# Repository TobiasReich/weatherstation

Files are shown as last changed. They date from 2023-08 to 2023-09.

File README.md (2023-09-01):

# Weatherstation

As part of my studies I wanted to experiment with the smallest devices and sensors I could get.
This became a local (indoor) weather station built up with an ESP32 and sensors.

If you are looking for a cheap weather station you might find this somewhere else. This is more a hobby, a kind of a playground for sensors and C programming.

## Overview

The idea is to
- use a cheap and low energy consuming ESP32 as base
- use a bunch of sensors for getting an idea of the environment
- draw the data on a waveshare e-paper display

## Devices

1. ESP32 device:
https://www.waveshare.com/wiki/E-Paper_ESP32_Driver_Board

1. E-Paper display:
I used the 400x300 pixel e-paper display from Waveshare: https://www.waveshare.com/4.2inch-e-paper-module.htm

1. Sensors:

I used the following sensors:

- Thermometer
- Barometer
- ~~Raindrop Sensor~~
- Humidity Sensor
- Soil Humidity sensor (for knowing whether I have to water the plants)
- Air Quality sensor (CO2 and TVOC)

Many came from here:

https://www.sunfounder.com/products/sensor-kit-v2-for-arduino?_pos=2&_sid=1bdf16cc9&_ss=r

Furthermore the device uses a soil moisture senesor from here:

https://www.seeedstudio.com/Grove-Capacitive-Moisture-Sensor-Corrosion-Resistant.html

And an air quality sensor from here:

https://wiki.seeedstudio.com/Grove-VOC_and_eCO2_Gas_Sensor-SGP30/

# Pinouts

This is not the exact model but it seems to have the same pinout. Sadly the documentation on Waveshare is not the best.

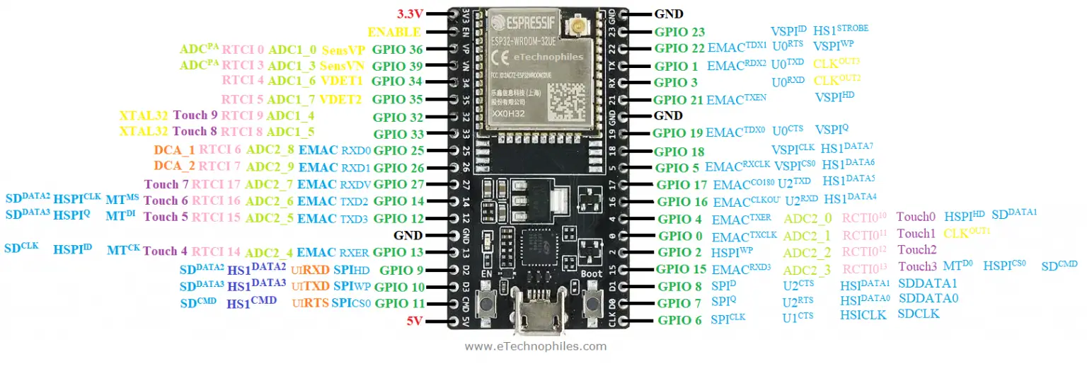
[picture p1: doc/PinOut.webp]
Pinout


The schematics look currently like that:
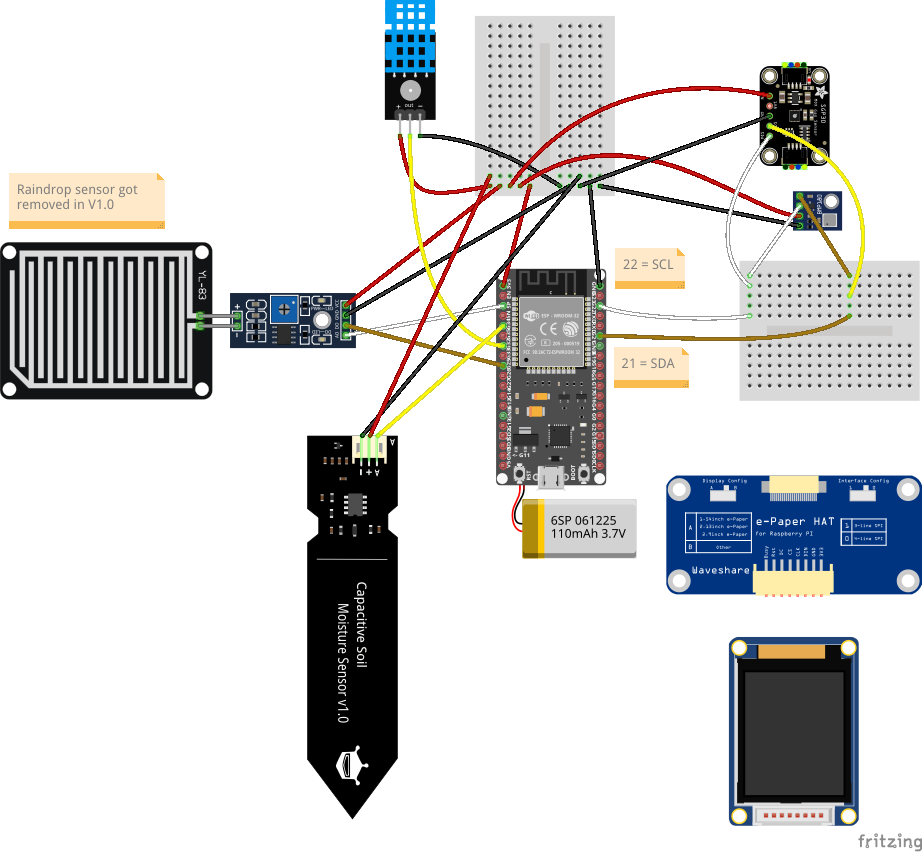
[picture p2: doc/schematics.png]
Schematics


The first version of it (which is in usage) looks like that (and in German only).

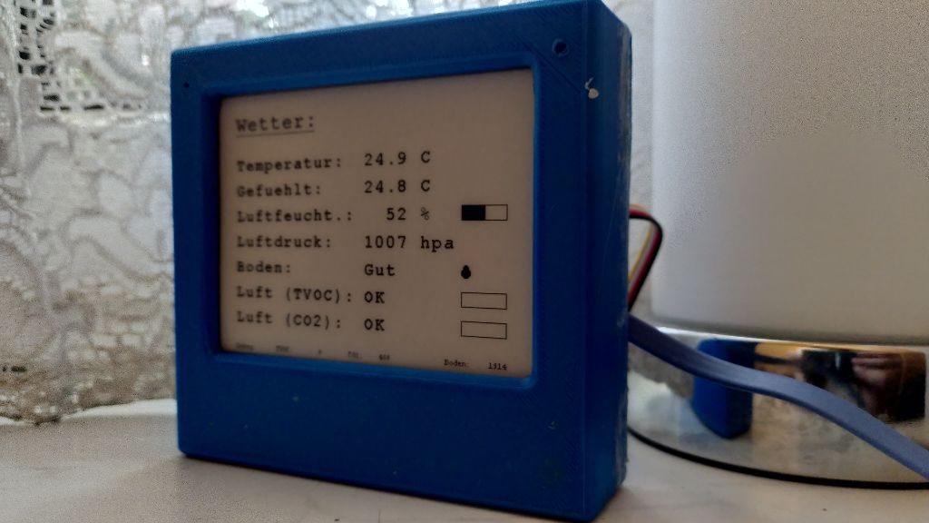
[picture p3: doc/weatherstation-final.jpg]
First test The final usage


Version 2 also got a graph showing the recent 10 hours (20 measurements) for TVOC and CO2 readings.
That way you can keep track of the situation. This might come handy in situations where you have the suspicion of raising values (e.g. over night, with a closed window).
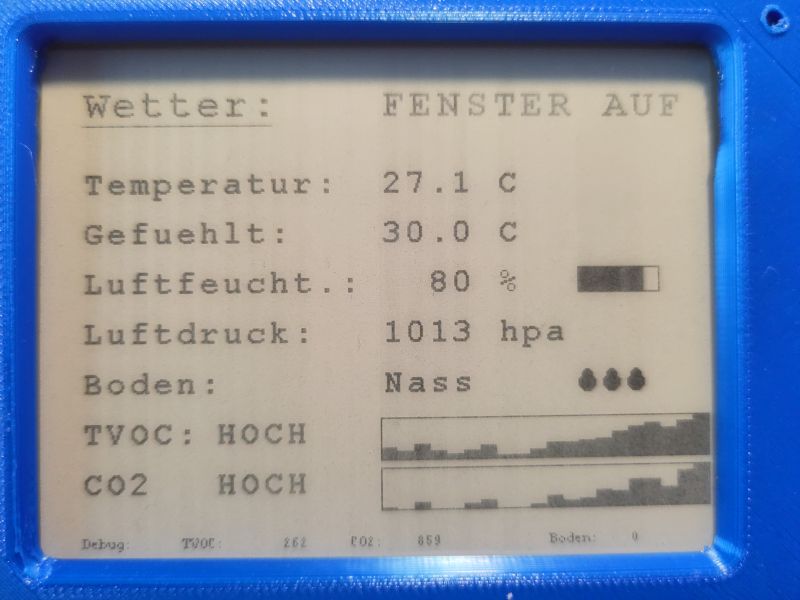
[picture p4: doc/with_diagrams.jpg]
Version 2 adding a diagram


## Barometer

- Black - GROUND
- Red - 3.3V
- White - GPIO 21 (DEFAULT SDA)
- Brown - GPIO 22 (DEFAULT SCL)
- I2C: 0x77

## ~~Raindrop Sensor~~

~~This is connected via a Raindrop Sensor (which connects again to the device).~~

- Black - GROUND
- Red - 3.3V
- White - GPIO 36 (ANALOG AO)
- Brown - GPIO 25 (D0)

Note: I removed it since it was not very useful. Placing it indoors made no sense, outdoors not much either (you see it anyway, you can measure it with the soil moisture sensor...). It just made things more complex and was useless.

## Humidity Sensor

- Black - GROUND
- Red - 3.3V
- Yellow - GPIO 32

## Soil Moisture Sensor

- Black - GROUND
- Red - 3.3V
- White - GPIO ??
- Brown - GPIO ??

Note that the soil moisture sensor is just an analog one. It checks the resistence and varies for example if you provide 3.3V or 5V to it.
Hence the setup might vary your constants.

I plugged it to 3.3 volt and defined the constants as

- SOIL_DRYNESS_HIGH 2000

- SOIL_DRYNESS_MEDIUM 1150

where the analog value goes higher the dryer the ground is.

## Air Quality Sensor

- Black - GROUND
- Red - 3.3V
- White - GPIO 21 (DEFAULT SDA)
- Brown - GPIO 22 (DEFAULT SCL)
- I2C: 0x58

NOTE: they share the same

I also calculate the "air quality" by very simple means.

These are the constants I use:

- VOC_LOW 25

- VOC_MED 75

- CO2_LOW 450

- CO2_MED 550

And I draw them on the display in a very simple graph, indicating the quality.
This surely can be done better.

# Known issues:

1. When there is rain on the rain sensor, the voltage it draws seems to be too high and the display doesn't refresh anymore. I therefore (and for it's limited usage) removed the sensor for version 1.

2. Also the case I printed comes with some drawbacks. Even as a physics enthusiast it took a while to realize that CO2 is heavier than O2. And with basically no opening in the case the CO2 value was rising over the time to higher and higher values. In any case you should avoid placing the air quality sensor at the bottom of the case! And add some holes to the rear side.

3. Turns out, the glue I was using for fusing the PLA casing, is evaporating "volatile particles" thus influencing the TVOC reading. A quick fix would be either to move the sensor outside or use a different glue. I guess in the long term it will reduce it's evaporation, too but the best solution might be a better case (with lots of openings and less glue required).

4. Furthermore you need to make sure the temperature sensor is not too close to the ESP32. In my example the heat from the processor is radiating to the temperature sensor leading to 1-2 degrees higher temperature.

I originally thought I could put it inside like this:

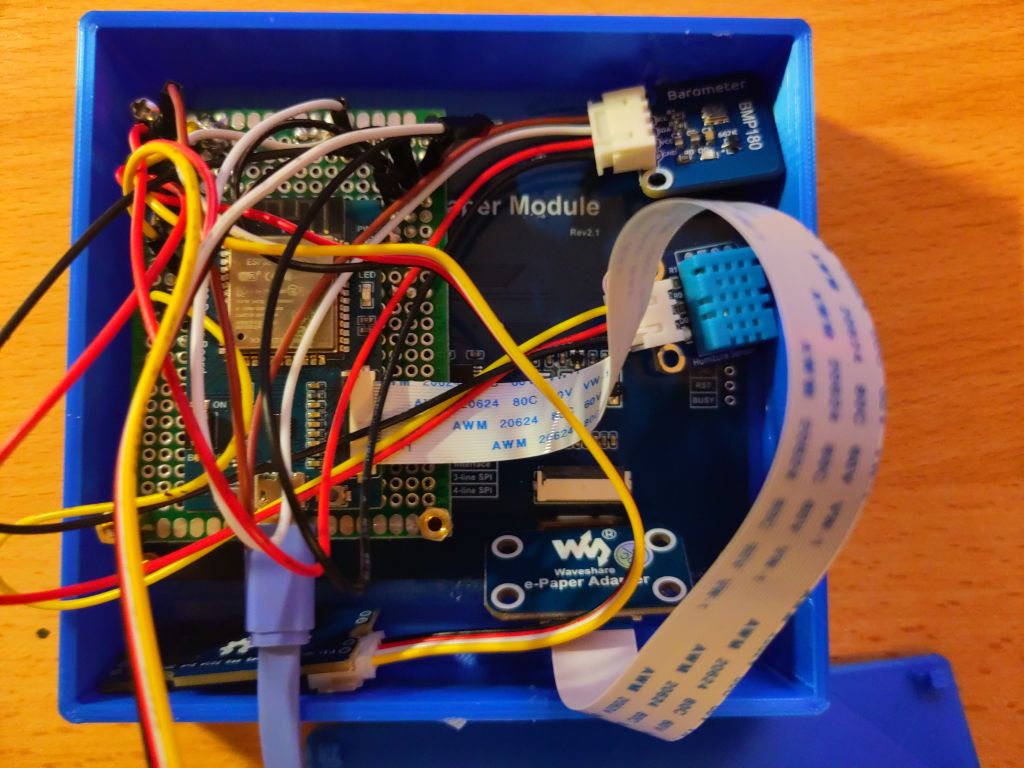
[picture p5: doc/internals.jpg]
First test the planned interior.


which would be still not great but not horrible either. However, with the tiny case I had to squeeze eveything to gether ending up with a crammed case where everything is right next to eachother. Version 2 has to be a little bigger!

# Schematics

I tried to use Fritzing for a better schematics diagram.

Since the software lacks some of the components I need, I used many of these repositories:

https://github.com/sunfounder/sunfounder-uno-and-mega-kit
https://github.com/jorgechacblogspot/librerias_fritzing
https://github.com/OgreTransporter/fritzing-parts-extra/tree/master
https://github.com/Seeed-Studio/fritzing_parts

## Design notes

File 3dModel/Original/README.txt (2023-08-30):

4.2" E-Paper Weather Station w/ ESP32 - Case by Wi_Zeus on Thingiverse: https://www.thingiverse.com/thing:2954579

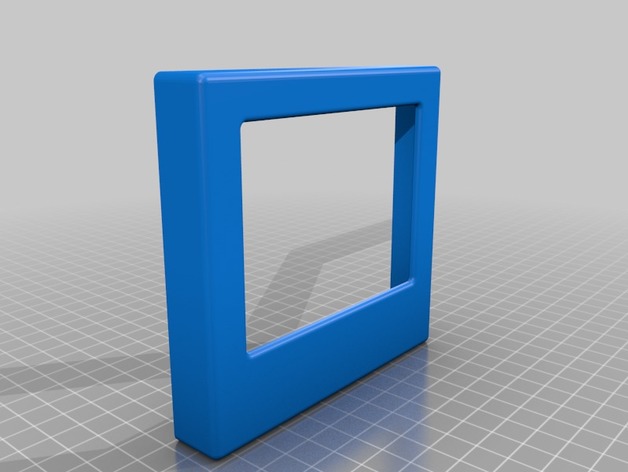
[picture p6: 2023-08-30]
3dModel/Original/images/4.2_Epaper_Weather_Station_Main_V3.jpg

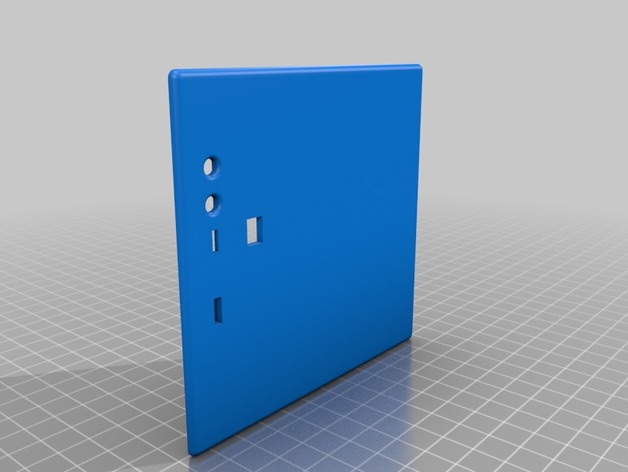
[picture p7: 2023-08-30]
3dModel/Original/images/4.2_Epaper_Weather_Station_Back_V3.jpg

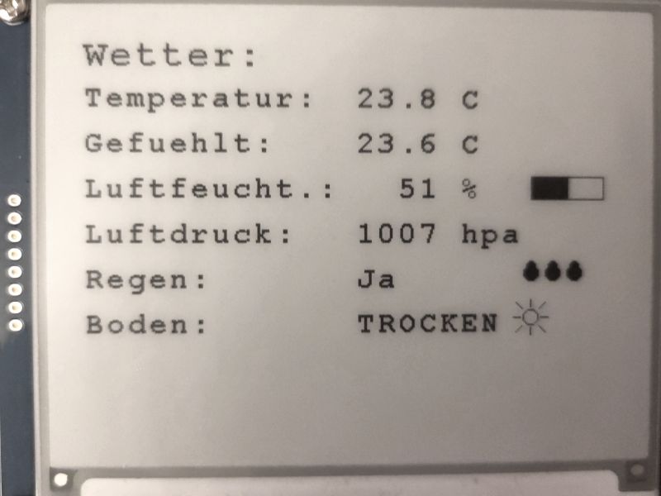
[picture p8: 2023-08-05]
doc/weatherstation-alpha01.jpg

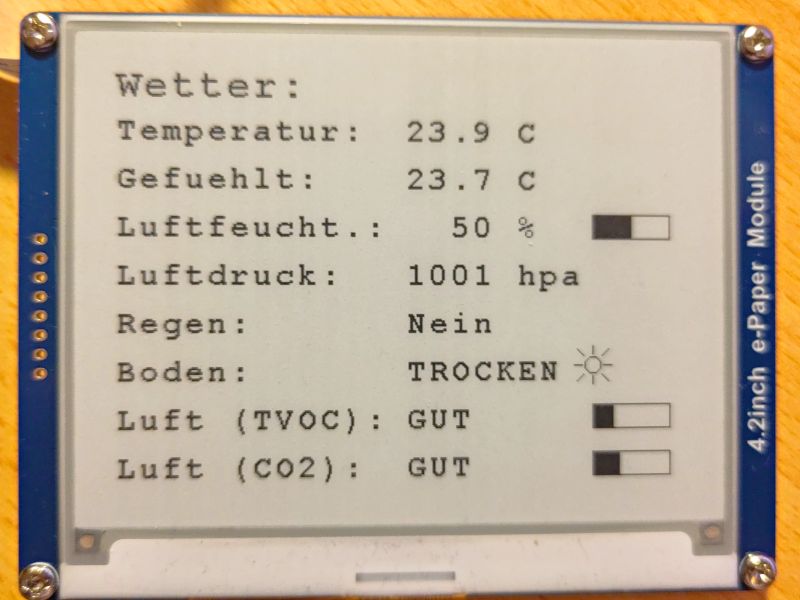
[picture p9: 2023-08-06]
doc/weatherstation-alpha02.jpg

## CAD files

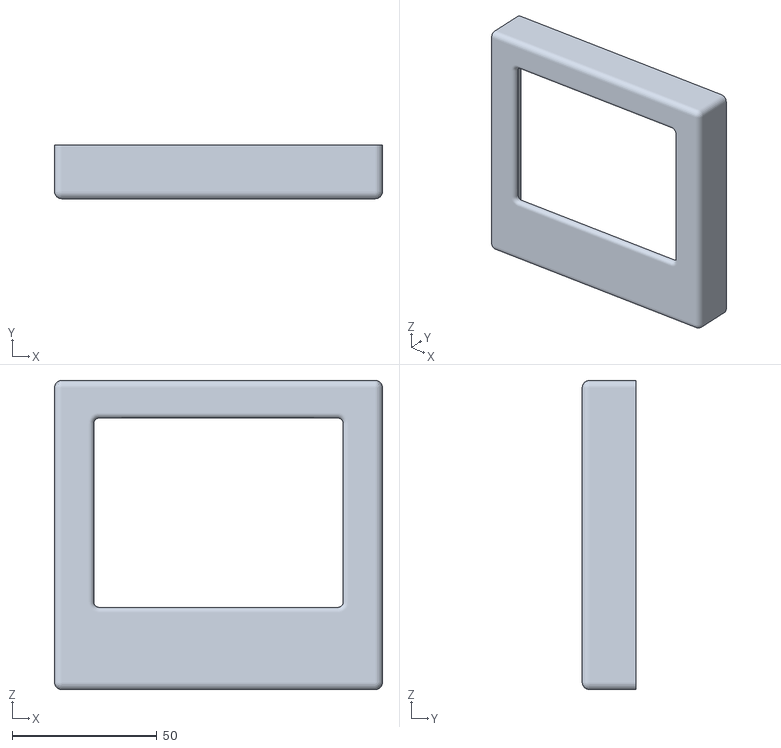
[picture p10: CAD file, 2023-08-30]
3dModel/Original/4.2_Epaper_Weather_Station_Main_V3.stl
113.2 x 18.5 x 106.7

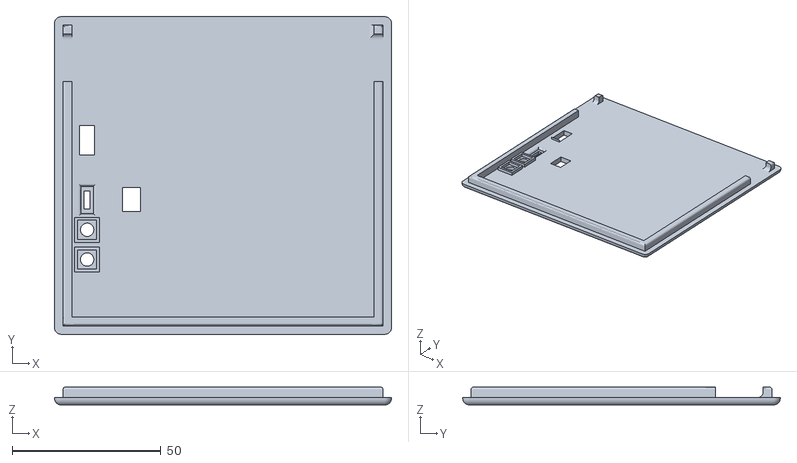
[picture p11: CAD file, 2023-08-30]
3dModel/GroveCutout/Back-GroveCutout.stl
113.2 x 106.7 x 6.00

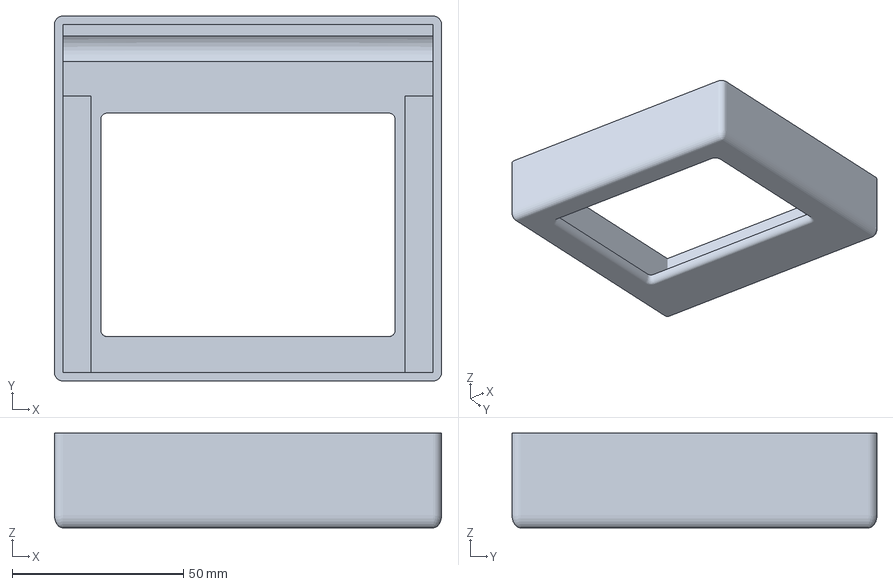
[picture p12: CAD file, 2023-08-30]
3dModel/Weatherstation-Front-150percent.3mf
113.2 x 106.7 x 27.8 mm

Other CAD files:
3dModel/Original/4.2_Epaper_Weather_Station_Back_V3.stl
3dModel/GroveCutout/Back-GroveCutout.blend

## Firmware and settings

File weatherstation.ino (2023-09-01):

#include <Adafruit_SGP30.h>
#include "DEV_Config.h"
#include "EPD.h"
#include "GUI_Paint.h"
#include "ImageData.h"
#include <stdlib.h>
#include <DHT.h>
#include <Wire.h> 
#include <Adafruit_BMP085.h> // Barometer - I2C:0x77
#include <pins_arduino.h>
#include "Adafruit_SGP30.h" // Air Quality I2C: 58


// 400x300, 4.2inch E-Ink raw display
// 9 x 7 cm display size
// https://www.waveshare.com/4.2inch-e-Paper.htm

#define DHTTYPE    DHT11  // DHT 11
#define DHTPIN 32         //7th from bottom right
DHT dht(DHTPIN, DHTTYPE); // Digital Humidity/Temperature sensor
Adafruit_BMP085 bmp;      // I2C controlled Barometer

UBYTE *BlackImage;
UWORD Imagesize = ((EPD_4IN2_WIDTH % 8 == 0) ? (EPD_4IN2_WIDTH / 8 ) : (EPD_4IN2_WIDTH / 8 + 1)) * EPD_4IN2_HEIGHT;

// Millis for the measurement update
// Note this also refreshes the screen (visibly).
// Since this can cause distractions and the weather 
// doesn't change that rapidly, it is perfectly fine to pick
// high values like
// 600000 -> every 10 minutes
// 1800000 -> every 30 minutes
// 3600000 -> every hour 
// or even more
uint32_t REFRESH_TIME = 1800000; 


// Rain Sensor
const int analogPin=A0;   //the AO of the module attach to A0 (PIN 36) (Left 3rd from top)
const int digitalPin=25;  //D0 attach to pin25 --> DAC_1 (GPIO25) (Left 9th from top)
int Astate=0;             //store the value of A0
boolean Dstate=0;         //store the value of D0

/*Soil Humidity
  - fully in Water          = 1100
  - mid humidity            = 1300
  - outside (at normal air) = 2100 */
#define SOIL_DRYNESS_HIGH 2000
#define SOIL_DRYNESS_MEDIUM 1150
#define SOIL_HUMIDITY_PIN 34 // Pin 34 5th from bottom right


// AIR QUALITY constants
#define VOC_LOW 25
#define VOC_MED 75
#define CO2_LOW 475
#define CO2_MED 600

#define DEBUG true
#define STORED_VALUES 20
#define DIAGRAM_HEIGHT 25
#define DIAGRAM_WIDTH 200

// Functions declaration
void drawSun(int x, int y);
void drawWaterdrop(int x, int y);
void drawProgressBar(int x, int y, int percent);
void showSplashscreen();
float getTemperature();
float getHumidty();
void processTemperatureHumidtyPressure(float temperature, float humidity);
void processRainSensor();
void processSoilHumidity();
void processAirQuality();


// --------------------------------------------


// Air quality
Adafruit_SGP30 sgp;

// The air quality calculation seems a bit fickle so it might be more reliable 
// to store the previous value and use the mean value
int previousTvoc = 0;
int previousCo2  = 400;

// For a "histogram" of previous values
int previousCo2Values[STORED_VALUES] = {0};
int previousTvocValues[STORED_VALUES] = {0};


uint32_t getAbsoluteHumidity(float temperature, float humidity) {
    // approximation formula from Sensirion SGP30 Driver Integration chapter 3.15
    const float absoluteHumidity = 216.7f * ((humidity / 100.0f) * 6.112f * exp((17.62f * temperature) / (243.12f + temperature)) / (273.15f + temperature)); // [g/m^3]
    const uint32_t absoluteHumidityScaled = static_cast<uint32_t>(1000.0f * absoluteHumidity); // [mg/m^3]
    return absoluteHumidityScaled;
}

// --- Air Quality

void drawSun(int x, int y){
  Paint_DrawCircle(x, y, 5, BLACK, DOT_PIXEL_1X1, DRAW_FILL_EMPTY);

  Paint_DrawLine(x-12, y, x-7, y, BLACK, DOT_PIXEL_1X1, LINE_STYLE_SOLID); // left
  Paint_DrawLine(x+12, y, x+7, y, BLACK, DOT_PIXEL_1X1, LINE_STYLE_SOLID); // right
  Paint_DrawLine(x, y-12, x, y-7, BLACK, DOT_PIXEL_1X1, LINE_STYLE_SOLID); // above
  Paint_DrawLine(x, y+12, x, y+7, BLACK, DOT_PIXEL_1X1, LINE_STYLE_SOLID); // below

  Paint_DrawLine(x-10, y-10, x-6, y-6, BLACK, DOT_PIXEL_1X1, LINE_STYLE_SOLID); // topleft
  Paint_DrawLine(x+10, y-10, x+6, y-6, BLACK, DOT_PIXEL_1X1, LINE_STYLE_SOLID); // topright
  Paint_DrawLine(x-10, y+10, x-6, y+6, BLACK, DOT_PIXEL_1X1, LINE_STYLE_SOLID); // topleft
  Paint_DrawLine(x+10, y+10, x+6, y+6, BLACK, DOT_PIXEL_1X1, LINE_STYLE_SOLID); // topright
}


void drawWaterdrop(int x, int y){
  Paint_DrawCircle(x, y+5, 5, BLACK, DOT_PIXEL_1X1, DRAW_FILL_FULL);
  Paint_DrawCircle(x, y, 3, BLACK, DOT_PIXEL_1X1, DRAW_FILL_FULL);
  Paint_DrawCircle(x, y-2, 1, BLACK, DOT_PIXEL_1X1, DRAW_FILL_FULL);
}


void drawProgressBar(int x, int y, int percent){
  if (percent > 100) {
    percent = 100;
  } else if (percent < 0){
    percent = 0;
  }
  Paint_DrawRectangle(x, y, x+50, y+15, BLACK, DOT_PIXEL_1X1, DRAW_FILL_EMPTY);
  Paint_DrawRectangle(x, y, x+(percent/2), y+15, BLACK, DOT_PIXEL_1X1, DRAW_FILL_FULL);
}


/** Draws a diagram of values. For simplicity I gave it a fixed size of 10 elements.
    the min parameter subtracts this value from all values so the min value becomes "0"
    in the graph
    1. find the max value of the array
    2. calculate the scale factor so we cann draw the diagram propperly
    3. draw bars (for simplicity) for each of the 10 values */
void drawDiagramm(int (&values)[STORED_VALUES], int x, int y, int min = 0){
  // Draw an empty graph in any case
  Paint_DrawRectangle(x, y, x+DIAGRAM_WIDTH, y+DIAGRAM_HEIGHT, BLACK, DOT_PIXEL_1X1, DRAW_FILL_EMPTY);

  // Calculate the values
  int bucketWidth = DIAGRAM_WIDTH / STORED_VALUES;
  int max = 0;
  float scale = 0.0;

  for(int i=0; i<STORED_VALUES; i++){
    if ((values[i]-min) > max){
      max = values[i] - min;
    }
  }

  // no max value found, no need to render a graph
  if (max == 0){
    Serial.println("\nNo values to print!");
    return;
  }

  // Calculate the scale all values have to be multiplied before they are drawn
  // E.g. a max of 100 with a diagram height of 50 leads to a scale of 0.5f
  // E.g. the 100 value will be scaled down to 50pixels
  scale = static_cast<float>(DIAGRAM_HEIGHT) / static_cast<float>(max);

  // Draw the graph now
  for(int i=0; i < STORED_VALUES; i++){
    int value = static_cast<float>(values[i]-min) * scale;
    // if the bucket is still filled with 0 values, we don't have to draw that
    if (value > 0){
      Paint_DrawRectangle(x+(i*bucketWidth), y+(DIAGRAM_HEIGHT - value),
                          x+((i+1)*bucketWidth)-1, y+DIAGRAM_HEIGHT, 
                          BLACK, DOT_PIXEL_1X1, DRAW_FILL_FULL);
    }
  }
}


void showSplashscreen() {
  Paint_NewImage(BlackImage, EPD_4IN2_WIDTH, EPD_4IN2_HEIGHT, 0, WHITE);
  Serial.println("SelectImage:BlackImage\r\n");
  Paint_SelectImage(BlackImage);
  Paint_Clear(WHITE);
  Paint_DrawString_EN(100, 140, "Wetterstation", &Font24, WHITE, BLACK);
  Paint_DrawLine(90, 165, 335, 165, BLACK, DOT_PIXEL_2X2, LINE_STYLE_DOTTED); // above
  EPD_4IN2_Display(BlackImage);
}


float getTemperature(){
  return dht.readTemperature();
}


float getHumidty(){
  return dht.readHumidity();
}

void processTemperatureHumidtyPressure(float temperature, float humidity){
  // Reading temperature or humidity takes about 250 milliseconds!
  // Sensor readings may also be up to 2 seconds 'old' (its a very slow sensor)
  //float humidity = dht.readHumidity();
  //float temperature = dht.readTemperature();
  int pressure = bmp.readPressure()/100;

  // Check if any reads failed and exit early (to try again).
  if (isnan(humidity) || isnan(temperature)) {
    Serial.println(F("Failed to read from DHT sensor!"));
  } else {
    // Compute heat index in Celsius (isFahreheit = false)
    float heatIndex = dht.computeHeatIndex(temperature, humidity, false);
    Serial.print(F("Humidity: "));
    Serial.print(humidity);
    Serial.print(F("%, Temperature: "));
    Serial.print(temperature);
    Serial.print(F("°C, Heat index: "));
    Serial.print(heatIndex);
    Serial.println(F("°C "));

    char tempbuffer [7];
    sprintf (tempbuffer, "%.1f C", temperature);
    
    char hicbuffer [7];
    sprintf (hicbuffer, "%.1f C", heatIndex);

    // Temperature
    Paint_DrawString_EN(20, 70, "Temperatur:", &Font20, WHITE, BLACK);
    Paint_DrawString_EN(200, 70, tempbuffer, &Font20, WHITE, BLACK);

    // Felt 
    Paint_DrawString_EN(20, 100, "Gefuehlt:", &Font20, WHITE, BLACK);
    Paint_DrawString_EN(200, 100, hicbuffer, &Font20, WHITE, BLACK);

    // Humidity
    char humidbuffer [7];
    sprintf (humidbuffer, "  %.0f %%", humidity);
    Paint_DrawString_EN(20, 130, "Luftfeucht.:", &Font20, WHITE, BLACK);
    Paint_DrawString_EN(200, 130, humidbuffer, &Font20, WHITE, BLACK);
    drawProgressBar(320, 130, (int)humidity);

    //Pressure
    char pressurebuffer [9];
    sprintf (pressurebuffer, "%4d hpa", pressure);
    Paint_DrawString_EN(20, 160, "Luftdruck:", &Font20, WHITE, BLACK);
    Paint_DrawString_EN(200, 160, pressurebuffer, &Font20, WHITE, BLACK);
  }
}


void processSoilHumidity(){
  int soilDryness = analogRead(SOIL_HUMIDITY_PIN);
  Serial.println(soilDryness);

  Paint_DrawString_EN(20, 190, "Boden:", &Font20, WHITE, BLACK);

  // print out the value you read:
  if (soilDryness > SOIL_DRYNESS_HIGH){
    // DRYEST
    Serial.println("DRY");
    Paint_DrawString_EN(200, 190, "TROCKEN", &Font20, WHITE, BLACK);
    drawSun(325, 195);  
  } else if (soilDryness > SOIL_DRYNESS_MEDIUM) {
    // MID HUMID
    Serial.println("MID");
    Paint_DrawString_EN(200, 190, "Gut", &Font20, WHITE, BLACK);
    drawWaterdrop(325, 195);
  } else {
    // WET
    Serial.println("Wet");
    Paint_DrawString_EN(200, 190, "Nass", &Font20, WHITE, BLACK);
    drawWaterdrop(325, 195);
    drawWaterdrop(340, 195);
    drawWaterdrop(355, 195);
  }

  if (DEBUG){
    char debugText[10 * sizeof(char)];
    std::sprintf(debugText, "%d", soilDryness);
    Paint_DrawString_EN(300, 290, "Boden:" , &Font8, WHITE, BLACK);
    Paint_DrawString_EN(350, 290, debugText , &Font8, WHITE, BLACK);
  }
}


void processAirQuality(float temperature, float humidity){
  if (! sgp.IAQmeasureRaw()) {
    Serial.println("Raw Measurement failed");
    Paint_DrawString_EN(20, 220, "Luft: Fehler 1", &Font20, WHITE, BLACK);
    return;
  }

  if (! sgp.IAQmeasure()) {
    Serial.println("Measurement failed");
    Paint_DrawString_EN(20, 220, "Luft: Fehler 2", &Font20, WHITE, BLACK);
    return;
  }

  // If you have a temperature / humidity sensor, you can set the absolute
  // humidity to enable the humditiy compensation for the air quality signals
  sgp.setHumidity(getAbsoluteHumidity(temperature, humidity));


  int tvoc = sgp.TVOC;
  int co2  = sgp.eCO2;
  Serial.print("TVOC "); Serial.print(tvoc); Serial.println(" ppb\t");
  Serial.print("eCO2 "); Serial.print(co2); Serial.println(" ppm");

  // in order to flatten air quality values (which are a bit fickle)
  // we calculate tvoc and co2 as the mean of this and the last measurement
  tvoc = (previousTvoc + tvoc) / 2; 
  co2  = (previousCo2 + co2) /2;

  boolean isHigh = false;

  Paint_DrawString_EN(20, 220, "TVOC:", &Font20, WHITE, BLACK);
  if(tvoc < VOC_LOW){
    Paint_DrawString_EN(100, 220, "OK", &Font20, WHITE, BLACK);
  } else if (tvoc < VOC_MED) {
    Paint_DrawString_EN(100, 220, "GUT", &Font20, WHITE, BLACK);
  } else {
    Paint_DrawString_EN(100, 220, "HOCH", &Font20, WHITE, BLACK);
    isHigh = true;
  }

  Paint_DrawString_EN(20, 250, "CO2", &Font20, WHITE, BLACK);
  if(co2 < CO2_LOW){
    Paint_DrawString_EN(100, 250, "OK", &Font20, WHITE, BLACK);
  } else if (co2 < CO2_MED) {
    Paint_DrawString_EN(100, 250, "GUT", &Font20, WHITE, BLACK);
  } else {
    Paint_DrawString_EN(100, 250, "HOCH", &Font20, WHITE, BLACK);
    isHigh = true;
  }

  // if any of the air quality values is "too high" a message "open the windows" appears
  if(isHigh){
    Paint_DrawString_EN(200, 20, "FENSTER AUF", &Font24, WHITE, BLACK);
  }

  if (DEBUG){
    // Writing some debug values    
    char airQualityText[10 * sizeof(char)];

    Paint_DrawString_EN(20, 290, "Debug: ", &Font8, WHITE, BLACK);
    std::sprintf(airQualityText, "%d", tvoc);
    Paint_DrawString_EN(80, 290, "TVOC: " , &Font8, WHITE, BLACK);
    Paint_DrawString_EN(140, 290, airQualityText , &Font8, WHITE, BLACK);

    Paint_DrawString_EN(180, 290, "CO2: " , &Font8, WHITE, BLACK);
    std::sprintf(airQualityText, "%d", co2);
    Paint_DrawString_EN(220, 290, airQualityText , &Font8, WHITE, BLACK);
  }

  // Diagram magic here
  // 1. shift all values of the "diagram array" to the left,
  // 2. add the current value to the end

  for (int i=0; i<STORED_VALUES; i++){
    previousTvocValues[i] = previousTvocValues[i+1];
    previousCo2Values[i] = previousCo2Values[i+1];
  }
  
  previousTvocValues[STORED_VALUES-1] = tvoc;
  previousCo2Values[STORED_VALUES-1] = co2;

  drawDiagramm(previousTvocValues, 200, 220);
  drawDiagramm(previousCo2Values, 200, 250, 400);
}


// --------------------------------------------------------
// --------------------------------------------------------
// --------------------------------------------------------


void setup(){
  DEV_Module_Init();

  Serial.begin(115200);
  while (!Serial) {
  ;  // wait for serial port to connect. Needed for native USB port only
  }

  Serial.println("Wetter Station");

  // Init the Barometer
  if (!bmp.begin()) {
    Serial.println("BMP180 Sensor not found ! ! !");
    while (1) { }
  }

  // Start Humidity / Temp sensor
  dht.begin();

  Serial.println(F("DHTxx Unified Sensor Example"));

  EPD_4IN2_Init_Fast();
  EPD_4IN2_Clear();
  DEV_Delay_ms(1500);
  
  if ((BlackImage = (UBYTE *)malloc(Imagesize)) == NULL) {
    Serial.println("Failed to apply for black memory...\r\n");
    while (1);
  }


  Serial.println("Starting SGP30");

  if (! sgp.begin()){
    Serial.println("SGP Air quality sensor not found :(");
    while (1);
  }

  Serial.print("Found SGP30 serial #");
  Serial.print(sgp.serialnumber[0], HEX);
  Serial.print(sgp.serialnumber[1], HEX);
  Serial.println(sgp.serialnumber[2], HEX);

  showSplashscreen();

  DEV_Delay_ms(500);
}


void loop() {
  // Draw the results screen
  Paint_Clear(WHITE);

  // Write parameters
  Paint_DrawString_EN(20, 20, "Wetter:", &Font24, WHITE, BLACK);
  Paint_DrawLine(20, 43, 135, 43, BLACK, DOT_PIXEL_1X1, LINE_STYLE_SOLID); // above

  // --- TEMPERATURE, HUMIDITY, PRESSURE ---
  float temp = getTemperature();
  float humidty = getHumidty();
  processTemperatureHumidtyPressure(temp, humidty);

  // ------ Soil Humidity ------
  processSoilHumidity();

  // ------ Air Quality ------
  processAirQuality(temp, humidty);

  // ------ Draw the image ------
  EPD_4IN2_Display(BlackImage);

  // Delay between measurements.
  DEV_Delay_ms(REFRESH_TIME);
}

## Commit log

2023-08-06 adding air quality sensor
    fixing documentation
    [weatherstation.ino]
2023-08-07 Adding schematics
    Adding a fritzing project and it's schematics to the documentation.
    Might make it easier for you (and me) to build this thing (again).
    [project.fzz]
2023-08-30 adding a better 3d model
    [4.2_Epaper_Weather_Station_Back_V3.stl, 4.2_Epaper_Weather_Station_Main_V3.stl, Back-GroveCutout.blend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]
2023-08-30 removing raindrop sensor
    updating some values (now that we have some space) but also a better indicator for bad air
2023-08-31 final fixes
    adding some debug messages
    updating documentation
    [weatherstation.ino]
2023-08-31 fixing the CO2 scale
    A "worst case" for air quality of 600 ppm was a bit too optimistic (when living in a city at least)
    [weatherstation.ino]
2023-09-01 adding diagrams
    Showing the last 20 entries (10 hours) users might get a better idea of changes.
    [project.fzz]
